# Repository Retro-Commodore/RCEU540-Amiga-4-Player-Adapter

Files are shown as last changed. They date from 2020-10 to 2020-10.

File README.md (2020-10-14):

# RCEU540-Amiga-4-Player-Adapter
An adapter that plugs into the Amiga's parallel port to grant 3rd and 4th joystick port.  
  
## BOM
2x db9 male (for wires)  
1x db25 male (for wires)  
  
### Optional  
2x 1x2 2.54mm/0.1" SIL header  
2x jumpers  
  
The optional part is to enable 5v supply to the joystick (i.e. autofire etc)  
  
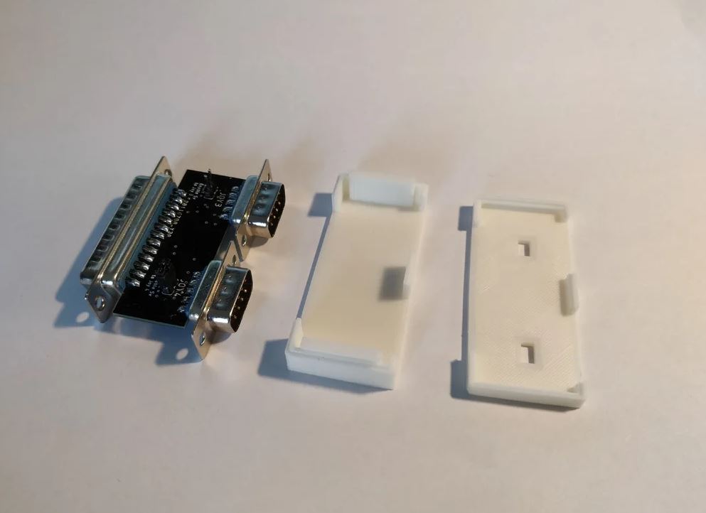
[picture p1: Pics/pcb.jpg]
pcb
  
  
## Casing
An adapter case is available on [Thingiverse](https://www.thingiverse.com/thing:4112671)  
  
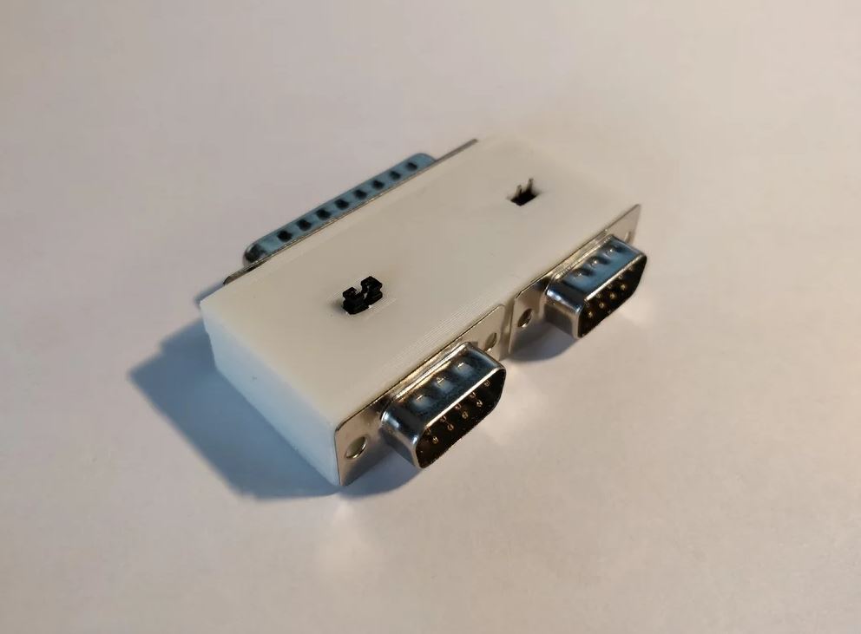
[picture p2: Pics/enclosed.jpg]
enclosed
  
  
## Notes
The adapter is quite stable plugged into the amiga and 2 joysticks connected to it.

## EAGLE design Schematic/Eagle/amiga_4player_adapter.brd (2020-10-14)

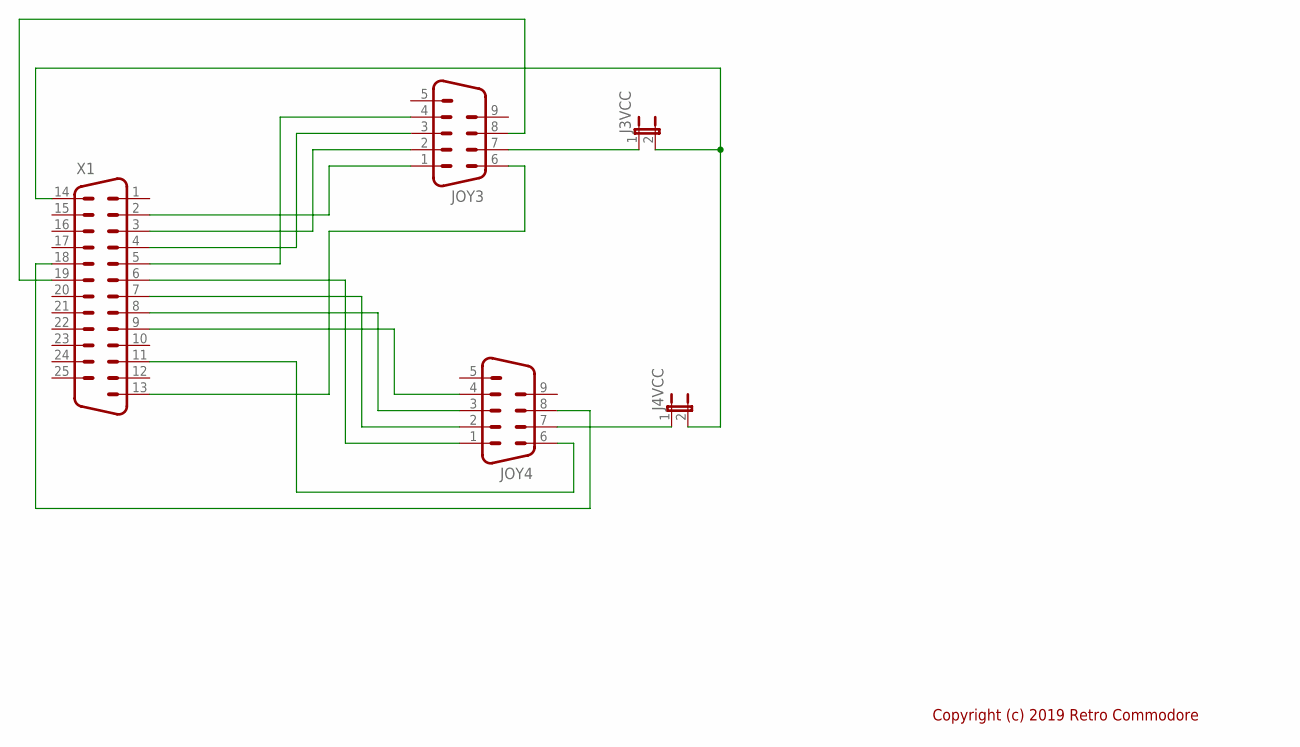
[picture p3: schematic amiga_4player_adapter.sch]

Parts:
J3VCC, J4VCC: JP1E; JP1
JOY3, JOY4: M09D
X1: M25D

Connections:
GND: JOY3.8, JOY4.8, X1.18, X1.19
J3_DOWN: JOY3.2, X1.3
J3_FIRE: JOY3.6, X1.13
J3_LEFT: JOY3.3, X1.4
J3_RIGHT: JOY3.4, X1.5
J3_UP: JOY3.1, X1.2
J3_VCC: J3VCC.1, JOY3.7
J4_DOWN: JOY4.2, X1.7
J4_FIRE: JOY4.6, X1.11
J4_LEFT: JOY4.3, X1.8
J4_RIGHT: JOY4.4, X1.9
J4_UP: JOY4.1, X1.6
J4_VCC: J4VCC.1, JOY4.7
VCC: J3VCC.2, J4VCC.2, X1.14

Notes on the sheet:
Copyright (c) 2019 Retro Commodore

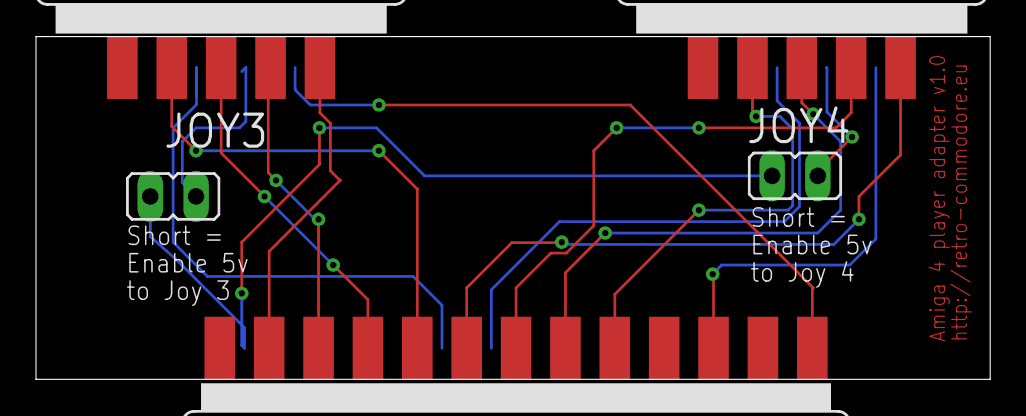
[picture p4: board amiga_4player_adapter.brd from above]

Board: 2 copper layers, 53.0 x 19.0 mm, 5 parts (0 on the bottom side), 14 nets.
